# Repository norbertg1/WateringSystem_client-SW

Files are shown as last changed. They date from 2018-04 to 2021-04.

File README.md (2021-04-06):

# Home watering system and weather station

The hardware is based on ESP8266. Its powered from LiFe battery which is chargerd from solar panel. The hardware wakes up every 10 minute (default), and login to mosquito message broker (on ubuntu) and publishes temperature, moisture, flow, etc.. If it is needed it can turn on the irrigation with H-bridge.
The connection between MySQL and Mosquitto is handled with short program written in Python.

**The PCB contains:** EPS8266, LiFe charger, battery voltage sensor, BMP280 sensor, soil moisture sensor, H-bridge for ball valve motor, flow meter.

#### **MySQL structure and settings:**

See: https://github.com/xnorbi/Watering-system/blob/master/server_on_ubuntu/MySQL/database_initialization_commands

For photos see other folder.

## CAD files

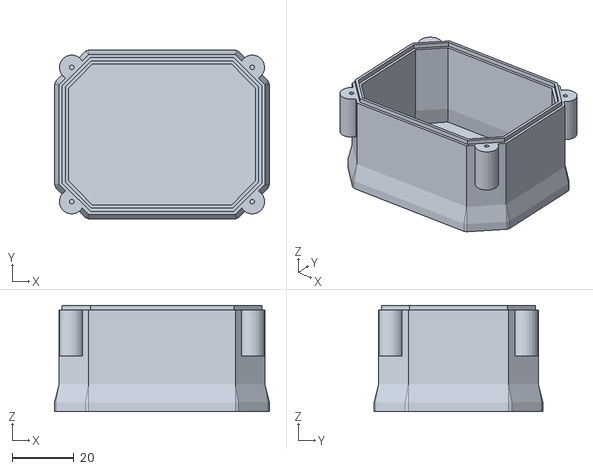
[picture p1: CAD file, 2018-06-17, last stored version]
tető/teto motoros szelepre with solar panel.stl
69.7 x 54.8 x 34.5

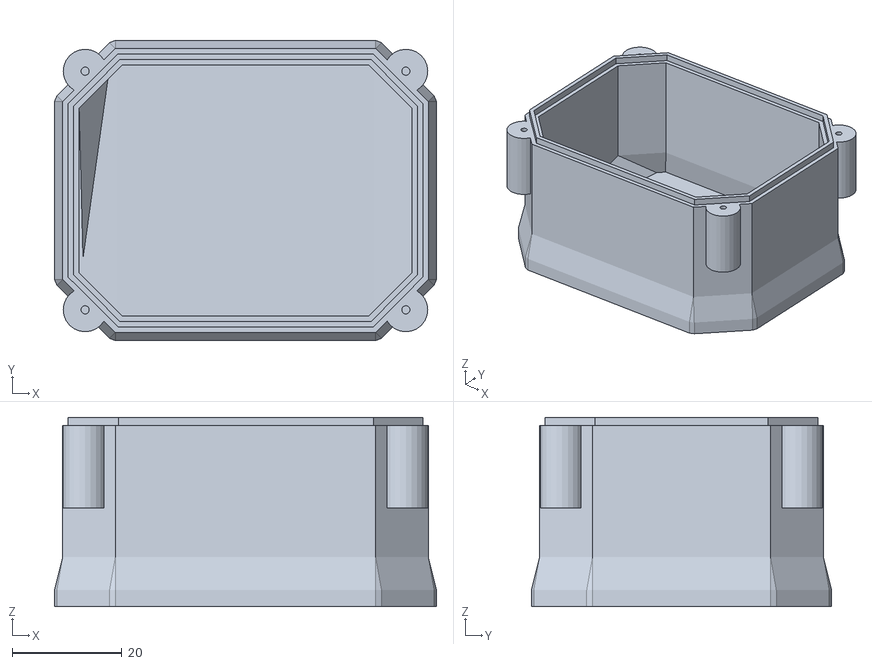
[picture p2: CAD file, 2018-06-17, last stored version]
tető/gal.stl
69.7 x 54.8 x 34.5

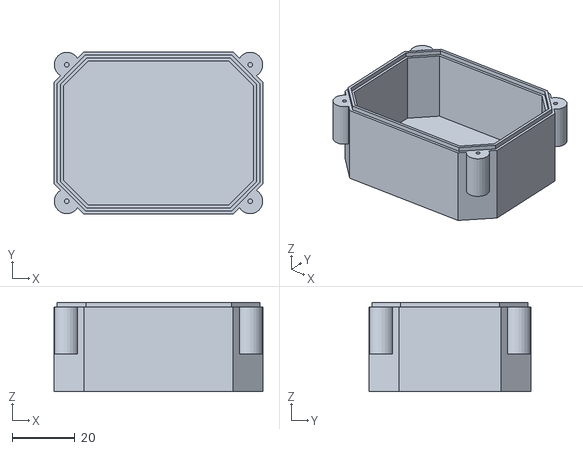
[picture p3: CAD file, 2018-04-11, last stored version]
tető/teto motoros szelepre.stl
66.7 x 51.8 x 28.5

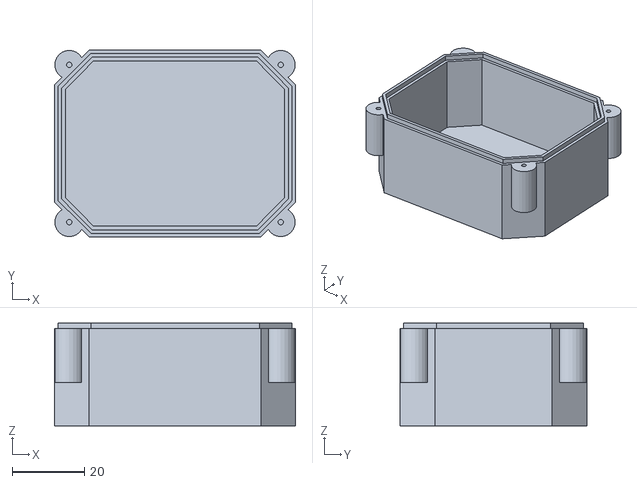
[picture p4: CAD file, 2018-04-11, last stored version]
tető/teto motoros szelepre modified.stl
66.7 x 51.8 x 28.5

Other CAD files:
tető/gal repaired.stl
tető/teto motoros szelepre with solar panel(1).stl
tető/teto motoros szelepre modified.skp
tető/teto motoros szelepre.skp

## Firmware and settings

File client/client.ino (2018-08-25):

/*
   This program login into ESP8266_locsolo_server on ubuntu. Gets the A0 pin status from the server then set it. Also send Vcc voltage and temperature, etc.
   When A0 is HIGH: ESP8266 loggin happens every 30seconds, if it is LOW ---> deep sleep for x seconds
   by Norbi

   v2.4.1 verzióban be kell kapcsolni a Tools --> Debug port ---> Serial beállítást. Ez nélkül ha megszakad a wifi kapcsolat 
   az mqtt_reconnect() funkció csak 3-4 próbálkozás alatt tud sikeresen visszacsatlakozni, felette már nem. Ezt a az opciót bekapcsolva viszont bármennyi próbálkozás után sikeres lehet az újracsatlakozás

   v2.4.1 verzióban Tools --> lwIP Variant --> v1.4 Compile from source opció (többit nem teszteltem, kivéve: defaulnál (v2 Lower Memory) nem működik) szükséges a TLS MQTT titkosított kapcsolat működéséhez

   Wifihez csatlakozás: Bekapcsolni a kapcsolóval, beírni a csatalkozási adatokat, majd ki be kapcsolni ismét a kapcsolóval.
*/
#include "client.h"
#include "certificates.h"
#include "communication.h"


//DHT dht(DHT_PIN, DHT_TYPE);
ESP8266WebServer server (80);
BMP280 bmp;
WiFiClientSecure espClient;
PubSubClient client(espClient);
File f;
#if SZELEP
ADC_MODE(ADC_VCC);
#endif

//const char* host = "192.168.1.100";
const char* mosquitto_user = "titok";
const char* mosquitto_pass = "titok";
char device_id[25];
int mqtt_port= 8883;

const char* serverIndex = "<form method='POST' action='/update' enctype='multipart/form-data'><input type='file' name='update'><input type='submit' value='Update'></form>";
uint32_t voltage;
double T, P;
float temp, temperature, moisture;
int RSSI_value;
int locsolo_state = LOW, on_off_command = LOW;
int sleep_time_seconds = 900;                  //when watering is off, in seconds
int delay_time_seconds = 60;                   //when watering is on, in seconds
int remote_update = 0, remote_log=0;
int flowmeter_int=0;
float flowmeter_volume, flowmeter_velocity;
int valve_timeout=0;
String ver;
int mqtt_done=0;

void setup() {
  if( ESP.getResetReason() != "Power on" && ESP.getResetReason() != "Deep-Sleep Wake" && ESP.getResetReason() != "Software/System restart") alternative_startup();
  Serial.begin(115200);
  delay(50);
  String ID = String(ESP.getChipId(), HEX) + "-" + String(ESP.getFlashChipId(), HEX);
  ID.toCharArray(device_id, 25); 
  format();
  f = create_file();
  println_out("\n-----------------------ESP8266 alive----------------------------------------\n");
  println_out(ESP.getResetReason());
  print_out("ID: ");   println_out(ID);
  print_out("MAC: ");   println_out(WiFi.macAddress());
  get_TempPressure();       //Azért az elején mert itt még nem melegedett fel a szenzor
  setup_pins();
  if (valve_state) valve_turn_off();  
  println_out("Setting up certificates");
  espClient.setCertificate(certificates_esp8266_bin_crt, certificates_esp8266_bin_crt_len);
  espClient.setPrivateKey(certificates_esp8266_bin_key, certificates_esp8266_bin_key_len);
  println_out("Setting up mqtt callback, wifi");
  client.setServer(MQTT_SERVER, mqtt_port);
  client.setCallback(mqtt_callback);
  setup_wifi();
  print_out("IP address:  ");
  println_out(String(WiFi.localIP()));
  print_out("RSSI: ");
  println_out(String(WiFi.RSSI()));
  ver = VERSION;  ver += '.';  ver += SZELEP;
  print_out("version:"); println_out(ver);
  if(voltage > MINIMUM_UPDATE_VOLTAGE) 
  {
    println_out("checking for update");
    t_httpUpdate_return ret = ESPhttpUpdate.update(MQTT_SERVER, 80, "/esp/update/esp8266.php", ver);
    http_update_answer(ret);
  }
  config_time();
}

void loop() {
  //valve_test();
  read_voltage();
  read_moisture();
  mqtt_reconnect();
  //flow_meter_calculate_velocity(); 
  if (client.connected()) {
    char buf_name[50];
    char buf[10];
    mqtt_done=0;
    client.loop();
    println_out("sending temperature");
    mqttsend_d(T, device_id, "/TEMPERATURE", 1);
    println_out("sending moisture");
    mqttsend_d(moisture, device_id, "/MOISTURE", 2);
    println_out("sending RSSI");
    mqttsend_i(WiFi.RSSI(), device_id, "/RSSI");
    println_out("sending voltage,etc..");
    mqttsend_d((float)voltage / 1000, device_id, "/VOLTAGE", 3);
    mqttsend_d(P, device_id, "/PRESSURE", 3);
    mqttsend_s(ver.c_str(), device_id, "/VERSION");
    mqttsend_s(ESP.getResetReason().c_str(), device_id, "/RST_REASON");
    mqttsend_d((float)flowmeter_int / FLOWMETER_CALIB_VOLUME, device_id, "/FLOWMETER_VOLUME_X", 2);    //ez azert kell hogy pontos legyen a ki be kapcsolás
    mqttsend_d((float)millis()/1000, device_id, "/AWAKE_TIME_X", 2);
    mqttsend_i(0, device_id, "/READY_FOR_DATA");
    //delay(3000);
    println_out("Waiting for commands");
    client.loop();
    for (int i = 0; i < 200; i++) {    //Ez mire van? torolni ha nem kell
      delay(100);
      client.loop();                  //Itt várok az adatra, talán szebben is lehetne
      if (mqtt_done == 5) break;
    }
  }

  println_out("Setting up webupdate if set");
  if (remote_update && valve_state() == 0)  web_update(remote_update);
  if (on_off_command && (float)voltage / 1000 > MINIMUM_VALVE_OPEN_VOLTAGE && !(client.state()))  valve_turn_on();
  if (!on_off_command || (float)voltage / 1000 < VALVE_CLOSE_VOLTAGE || (client.state()))        valve_turn_off();
  if (valve_state() != 1) {       //ha a szelep nincs nyitva
    if (client.connected()) {
      char buff_f[10];
      char buf_name[50];
      print_out("Valve state: "); println_out(String(valve_state()));
      mqttsend_i(0, device_id, "/ON_OFF_STATE");
      //mqttsend_d(flowmeter_volume, device_id, "/FLOWMETER_VOLUME", 2);      //ez törölhető csak figyelem van-e indokolatlan megszakítás
      //mqttsend_d(flowmeter_velocity, device_id, "/FLOWMETER_VELOCITY", 2);  //ez törölhető csak figyelem van-e indokolatlan megszakítás
      mqttsend_d((float)millis()/1000, device_id, "/AWAKE_TIME", 2);
      mqttsend_i(0, device_id, "/END");
      delay(100);
      client.disconnect();
    }
    go_sleep(SLEEP_TIME);    
  }
  else   {                        //ha a szelep nyitva van
    print_out("Valve state: "); println_out(String(valve_state()));
    flow_meter_calculate_velocity();
    mqtt_reconnect();
    if (client.connected()) {
      char buff_f[10];
      char buf_name[50];
      client.loop();
      mqttsend_i(1, device_id, "/ON_OFF_STATE");
      mqttsend_d(flowmeter_volume, device_id, "/FLOWMETER_VOLUME", 2);
      mqttsend_d(flowmeter_velocity, device_id, "/FLOWMETER_VELOCITY", 2);
      mqttsend_d((float)millis()/1000, device_id, "/AWAKE_TIME", 2);
      mqttsend_i(0, device_id, "/END");
      client.loop();
      delay(100);
      client.disconnect();
    }
    print_out("time in awake state: "); print_out(String((float)millis()/1000)); println_out(" s");
    println_out("delay");
    delay(DELAY_TIME);
    on_off_command = 0;
    detachInterrupt(FLOWMETER_PIN);
    digitalWrite(GPIO15, LOW);
    get_TempPressure();         //Nyitott szelepnél minden újracsatlakozásnál mérek hőmérsékletet és légnyomást
    digitalWrite(GPIO15, HIGH);
    attachInterrupt(FLOWMETER_PIN, flow_meter_interrupt, FALLING);
  }
}

void valve_turn_on() {
#if SZELEP
  digitalWrite(GPIO15, HIGH); //VOLTAGE BOOST
  println_out("Valve_turn_on()");
  pinMode(FLOWMETER_PIN, INPUT);
  attachInterrupt(FLOWMETER_PIN, flow_meter_interrupt, FALLING);
  digitalWrite(VALVE_H_BRIDGE_RIGHT_PIN, 0);
  digitalWrite(VALVE_H_BRIDGE_LEFT_PIN, 1);
  uint32_t t = millis();
  while (!digitalRead(VALVE_SWITCH_TWO) && (millis() - t) < MAX_VALVE_SWITCHING_TIME) {
    delay(100);
  }
  if (valve_state) locsolo_state = HIGH;
  if((millis() - t) > MAX_VALVE_SWITCHING_TIME)  {println_out("Error turn on timeout reached");  valve_timeout=1;}
#endif
}

void valve_turn_off() {
#if SZELEP
  bool closing_flag=0;
  println_out("Valve_turn_off");
  uint16_t cnt = 0;
  digitalWrite(VALVE_H_BRIDGE_RIGHT_PIN, 1);
  digitalWrite(VALVE_H_BRIDGE_LEFT_PIN, 0);
  uint32_t t = millis();
  while (!digitalRead(VALVE_SWITCH_ONE) && (millis() - t) < MAX_VALVE_SWITCHING_TIME) {
    delay(100);
    closing_flag=1;
  }
  if (closing_flag==1)  {
    flow_meter_calculate_velocity();
    mqttsend_d(flowmeter_volume, device_id, "/FLOWMETER_VOLUME", 2);
    mqttsend_d(flowmeter_velocity, device_id, "/FLOWMETER_VELOCITY", 2);
  }
  if (!valve_state) locsolo_state = LOW;
  digitalWrite(GPIO15, LOW);  //VOLTAGE_BOOST
  detachInterrupt(FLOWMETER_PIN); 
  if((millis() - t) > MAX_VALVE_SWITCHING_TIME)  {println_out("Error turn off timeout reached");  valve_timeout=1;}
#endif
}

int valve_state() {
#if SZELEP
  int ret=0;
  if(digitalRead(VALVE_SWITCH_TWO) && !digitalRead(VALVE_SWITCH_ONE))    {ret=1;}
  if(!digitalRead(VALVE_SWITCH_TWO) && digitalRead(VALVE_SWITCH_ONE))    {ret=0;}
  if(digitalRead(VALVE_SWITCH_TWO) && digitalRead(VALVE_SWITCH_ONE))     {ret=2;}
  if(!digitalRead(VALVE_SWITCH_TWO) && !digitalRead(VALVE_SWITCH_ONE))   {ret=3;}
  if(valve_timeout) { ret+=10;}
  return ret;  
  //return digitalRead(VALVE_SWITCH_TWO);
#else
  return 0;
#endif
}

void valve_test(){
  while(1){
    valve_turn_off();
    valve_turn_on();
    delay(100);
    }
}

void setup_pins(){
  pinMode(GPIO15, OUTPUT);
  pinMode(VALVE_H_BRIDGE_RIGHT_PIN, OUTPUT);
  pinMode(VALVE_H_BRIDGE_LEFT_PIN, OUTPUT);
  pinMode(RXD_VCC_PIN, OUTPUT);
  pinMode(VALVE_SWITCH_ONE, INPUT);
  pinMode(VALVE_SWITCH_TWO, INPUT);
}

void go_sleep_callback(WiFiManager *myWiFiManager){
  go_sleep(SLEEP_TIME_NO_WIFI);
}

void go_sleep(float microseconds){
  valve_turn_off();
  //WiFi.disconnect();  //nehezen akart ezzel visszacsatlakozni
  if (remote_log)  send_log();
  espClient.stop();
  print_out("time in awake state: "); print_out(String((float)millis()/1000)); println_out(" s");
  Serial.print("time in awake state: "); Serial.print((float)millis()/1000); Serial.println(" s");
  if(microseconds - micros() > MINIMUM_DEEP_SLEEP_TIME){  //korrekcio a bekapcsolva levo idore 
    microseconds = microseconds - micros();
  }
 
  time_t now = time(nullptr);
  if(now == 0 && rtcData.valid){
    rtcData.epoch += (time_t)millis()/1000; //Az RTCben tárolt epoch értékehz hozzáadom a bekapolcst állapotban levő időhosszt
    now = rtcData.epoch;  //Az RTCben tárolt érték lesz a jelenlegi időpont
  }
  else rtcData.epoch = now;
  rtcData.epoch += (time_t)microseconds/1000000; //Az RTCbet tárolt epoch értékét megnövelem az deepsleep állapotban levő időhosszal
  println_out("");
  println_out(ctime(&now));
  RTC_save();
  print_out("Entering in deep sleep for: "); print_out(String((float)microseconds/1000000)); println_out(" s");
  close_file();
  delay(100);
  ESP.deepSleep(microseconds); //az elozo sort vonom ki
  delay(100);
}

void flow_meter_interrupt(){
  flowmeter_int++;
}

void flow_meter_calculate_velocity(){
  static int last_int_time = 0, last_int = 0;;

  flowmeter_volume = (float)flowmeter_int / FLOWMETER_CALIB_VOLUME;
  flowmeter_velocity = ((float)(flowmeter_int - last_int) / (((int)millis() - last_int_time)/1000))/FLOWMETER_CALIB_VELOCITY;
  //if (flowmeter_volume == 0) flowmeter_velocity=0;
  last_int_time = millis();
  last_int = flowmeter_int;

  print_out("Flowmeter volume: "); print_out(String(flowmeter_volume)); println_out(" L");
  print_out("Flowmeter velocity: "); print_out(String(flowmeter_velocity)); println_out(" L/min");
}

void read_voltage(){
#if !SZELEP  
  digitalWrite(GPIO15, 0);        //FSA3157 digital switch
  digitalWrite(RXD_VCC_PIN, 1);
  delay(100); //2018.aug.25
  voltage = 0;
  for (int j = 0; j < 20; j++) voltage+=analogRead(A0); // for new design
  //voltage = (voltage / 20)*4.7272*1.039;                         //4.7272 is the resistor divider value, 1.039 is empirical for ESP8266
  voltage = (voltage / 20)*4.7272*0.957;                                 //82039a-1640ef, 2018.aug.15
  print_out("Voltage:");  println_out(String(voltage));
  digitalWrite(RXD_VCC_PIN, 0);
#else
  voltage = 0;
  for (int j = 0; j < 10; j++) {voltage+=ESP.getVcc(); /*Serial.println(ESP.getVcc());*/}
  voltage = (voltage / 10) - VOLTAGE_CALIB; //-0.2V
  print_out("Voltage:");  println_out(String(voltage));
#endif
  }

void read_moisture(){  
#if !SZELEP
  digitalWrite(GPIO15, 1);          //FSA3157 digital switch
  delay(100);
  moisture = 0;
  for (int j = 0; j < 20; j++) moisture += analogRead(A0);
  moisture = (((float)moisture / 20) / 1024.0) * 100;
  print_out("Moisture:");  println_out(String(moisture));
  digitalWrite(GPIO15, 0);
  delay(10);
#endif  
}

void get_TempPressure(){
  
  if (!bmp.begin(SDA,SCL))  {
    println_out("BMP init failed!");
    bmp.setOversampling(16);
  }
  else {println_out("BMP init success!"); bmp.setOversampling(16);}
  double t = 0, p = 0;
  for (int i = 0; i < 3; i++) {
    delay(bmp.startMeasurment());
    bmp.getTemperatureAndPressure(T, P);
    t += T;
    p += P;
  }
  T = t / 3;
  P = p / 3;
  print_out("T=");     print_out(String(T));
  print_out("   P=");  println_out(String(P));
}

void http_update_answer(t_httpUpdate_return ret){
  switch(ret) {
    case HTTP_UPDATE_FAILED:
      println_out("[update] Update failed.");
      break;
    case HTTP_UPDATE_NO_UPDATES:
      println_out("[update] Update no Update.");
      break;
    case HTTP_UPDATE_OK:
      println_out("[update] Update ok."); // may not called we reboot the ESP
      break;    
  }
}

File create_file(){
#if FILE_SYSTEM  
  SPIFFS.begin();
  char buff[13];
  sprintf (buff, "%s%s", "/", device_id);
  File f = SPIFFS.open(buff, "a+");
  if (!f) {
    Serial.println("log file open failed");
    SPIFFS.remove(buff);
    format_now();
  }
  if(f.size() > MAX_LOG_FILE_SIZE){      //Ha tul nagy
    f.close();
    SPIFFS.remove(buff);
    File f = SPIFFS.open(buff, "a+");
  }
  f.print("\nfile size:");
  f.print(f.size());
  Serial.print("\nfile size:");
  Serial.print(f.size());
  return f;
#endif
}

void close_file(){
#if FILE_SYSTEM
  f.close();
#endif
}

void print_out(String str){
#if SERIAL_PORT  
  Serial.print(str);
#endif
#if FILE_SYSTEM  
  f.print(str);
#endif
}

void println_out(String str){
#if SERIAL_PORT
  Serial.println(str);
  Serial.print((float)millis()/1000); Serial.print(":");
#endif
#if FILE_SYSTEM
  f.println(str);
  f.print((float)millis()/1000); f.print(":");
#endif
}

void config_time(){
#ifdef CONFIG_TIME
  configTime(2 * 3600, 3600, "pool.ntp.org", "time.nist.gov", "time.google.com");
  print_out("Get current time request");
#endif
}

void format(){
#if FILE_SYSTEM
  SPIFFS.begin();
  if (!SPIFFS.exists("/formok")) {
    Serial.println("Please wait 30 secs for SPIFFS to be formatted");
    if(SPIFFS.format()) Serial.println("Spiffs formatted");
    File file = SPIFFS.open("/formok", "w");
    if (!file) {
        Serial.println("file open failed");
    } else {
        file.println("Format Complete");
        file.close();
        Serial.println("format file written and closed");
    }
  } else {
    println_out("SPIFFS is formatted. Moving along...");
  }
#endif
}

void format_now(){
#if FILE_SYSTEM
  if(SPIFFS.format()) Serial.println("Spiffs formatted");
  else Serial.println("Spiffs format failed");
#endif
}

void alternative_startup(){
  SPIFFS.end();
  setup_wifi();
  t_httpUpdate_return ret = ESPhttpUpdate.update(MQTT_SERVER, 80, "/esp/update/esp8266.php", ver);
  http_update_answer(ret);
}

void RTC_save(){
  print_out("\nSaving BSSID, channel and time to RTC memory\n");
  rtcData.crc32 = calculateCRC32( ((uint8_t*)&rtcData) + 4, sizeof( rtcData ) - 4 );
  ESP.rtcUserMemoryWrite( 0, (uint32_t*)&rtcData, sizeof( rtcData ) );
}

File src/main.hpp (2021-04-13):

#ifndef MAIN_H
#define MAIN_H
/*
   This program login into ESP8266_locsolo_server on ubuntu. Gets the A0 pin status from the server then set it. Also send Vcc voltage and temperature, etc.
   When A0 is HIGH: ESP8266 loggin happens every 30seconds, if it is LOW ---> deep sleep for x seconds
   by Norbi

   3V alatt ne nyisson ki a szelep, de ha nyitva van akkor legyen egy deltaU feszĂĽltsĂ©g ami alatt csukodk be (pl 2.9V)
*/
#define ESP32
#include <Arduino.h>
#include "FS.h"
#include <PubSubClient.h>
//#include <ESP8266httpUpdate.h>
#include "HTTPUpdate.h"

//----------------------------------------------------------------settings---------------------------------------------------------------------------------------------------------------------------------------------//
#define WIFI_CONNECTION_TIMEOUT           30                              //Time for connecting to wifi in seconds
#define WIFI_CONFIGURATION_PAGE_TIMEOUT   300                             //when cannot connect to saved wireless network, in seconds, this is the time until we can set new SSID in seconds
#define MAX_VALVE_SWITCHING_TIME_SECONDS  20                              //The time when valve is switched off in case of broken microswitch or mechanical failure in seconds
#define WEB_UPDATE_TIMEOUT_SECONDS        300                             //The time out for web update server in seconds 
#define SLEEP_TIME_NO_WIFI_SECONDS        30//3600                            //When cannot connect to wifi network, sleep time between two attempts
#define MINIMUM_DEEP_SLEEP_TIME_SECONDS   60                              //in seconds
//---------------------------------------------------------------End of settings---------------------------------------------------------------------------------------------------------------------------------------//

//------------------------------------------------------------------------Do not edit------------------------------------------------------------------------------------------------
#define MINIMUM_DEEP_SLEEP_TIME           (long long) MINIMUM_DEEP_SLEEP_TIME_SECONDS * 1000000
#define SLEEP_TIME_NO_WIFI                (long long) SLEEP_TIME_NO_WIFI_SECONDS * 1000000    
#define SLEEP_TIME                        (long long) sleep_time_seconds * 1000000            //when watering is off, in microseconds
#define DELAY_TIME                        delay_time_seconds * 1000               //when watering is on, in miliseconds
#define WEB_UPDATE_TIMEOUT                WEB_UPDATE_TIMEOUT_SECONDS  * 1000      //time out for web update server
#define MAX_VALVE_SWITCHING_TIME          MAX_VALVE_SWITCHING_TIME_SECONDS*1000
#define DHT_TYPE                          DHT22
/*#define DHT_PIN                           0     //<---- innet kikommentezni oldhoz
#define VALVE_H_BRIDGE_RIGHT_PIN          12
#define VALVE_H_BRIDGE_LEFT_PIN           4
#define VALVE_SWITCH_ONE                  14
#define VALVE_SWITCH_TWO                  13
#define GPIO15                            15      //ennek kene lennie a voltage boost EN pinnek és az FSA3157 switch pinnek is
#define SCL                               5
#define SDA                               2
#define FLOWMETER_PIN                     5  */   //<---- eddig
#define RXD_VCC_PIN                       3
#define TXD_PIN                           1
#define VOLTAGE_CALIB                     230
#define MQTT_SERVER                       "locsol.dynamic-dns.net"
#define FTP_SERVER                        "192.168.1.101"
#define FLOWMETER_CALIB_VOLUME            450.0 //Pulses per Liter: 450
#define FLOWMETER_CALIB_VELOCITY          7.5   //Pulse frequency (Hz) / 7.5 = flow rate in L/min
#define MINIMUM_UPDATE_VOLTAGE            3.1   //If valve is closed
#define MINIMUM_VALVE_OPEN_VOLTAGE        3.1   //If valve is closed
#define VALVE_CLOSE_VOLTAGE               3.05   //If valve is open
#define MAX_LOG_FILE_SIZE                 409600
#define SZELEP                            0
#define FILE_SYSTEM                       0
#define SERIAL_PORT                       1
#define CONFIG_TIME                       1
//--------------------------------------------------------------------End----------------------------------------------------------------------------------------------------------------------------------------------------//
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

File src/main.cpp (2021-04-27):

/*
 
   Wifihez csatlakozás: Bekapcsolni a kapcsolóval, beírni a csatalkozási adatokat, majd ki be kapcsolni ismét a kapcsolóval.

*/
#include "main.hpp"

WiFiClient WifiClient;
File f;

//const char* host = "192.168.1.100";
char device_id[16];
int mqtt_port = 8883;
int sleep_time_seconds = 900;                  //when watering is off, in seconds
int delay_time_seconds = 60;                   //when watering is on, in seconds
int remote_update = 0, remote_log=0;

String ver;
String ID ;

WiFiClientSecure WifiSecureClient;
mqtt mqtt_client(WifiSecureClient);

valve_control Valve;
flowmeter Flowmeter;
voltage Battery;
moisture Soil;
thermometer Thermometer;
humiditySensor HumiditySensor;
pressureSensor PressureSensor;

void setup() {
  Serial.begin(115200);
  println_out("\n-----------------------ESP8266 alive-----------------------------------------\n");
  println_out("Reset reason for CPU0:");
  println_out(reset_reason(0));
  println_out("Reset reason for CPU1:");
  println_out(reset_reason(1));
  if( reset_reason(0) != "POWERON_RESET" && reset_reason(0) != "SW_RESET" && reset_reason(0) != "DEEPSLEEP_RESET") alternative_startup();  //Ez azért hogy ha hiba volna a programban akkor is újarindulás után OTAn frissíthető váljon a rendszer
  ID = String((uint32_t)(ESP.getEfuseMac() >> 32), HEX) + String((uint32_t)ESP.getEfuseMac(), HEX);  //String function doesnt know uint64_t
  ID.toCharArray(device_id, 16);
  format();
  f = create_file();
  RTC_validateCRC();
  setup_wifi();
  print_out("SDK: ");   println_out(ESP.getSdkVersion());
  print_out("Version: "); println_out(VERSION);
  print_out("ID: ");   println_out(ID);
  print_out("MAC: ");   println_out(WiFi.macAddress());
  setup_pins();
  Thermometer.read();
  HumiditySensor.read();
  PressureSensor.read();
  Battery.read_voltage();
  Soil.read_moisture();
  //if (Valve.state() && !Valve.winter_state) valve_turn_off();    //EEPROMba vagy SPIFFbe tarolni, hogy epp winter state van-e? utanna ellenorizni!!!
  if (Valve.state()) Valve.turn_off();
  Wait_for_WiFi();
  print_out("IP address:  ");
  println_out(String(WiFi.localIP().toString()));
  print_out("RSSI: ");
  println_out(String(WiFi.RSSI()));
  config_time();
  WifiSecureClient.setCACert(root_CA_cert);
  WifiSecureClient.setPrivateKey(ESP_RSA_key);
  WifiSecureClient.setCertificate(ESP_CA_cert);
  mqtt_client.setServer(MQTT_SERVER, mqtt_port);
  mqtt_client.setCallback(mqtt_callback);
  Serial.print("WifiSecureClient: "); Serial.println(WifiSecureClient.remoteIP());
  if((float)Battery.voltage/1000 > MINIMUM_UPDATE_VOLTAGE) 
  {
    println_out("Checking for update!");
    t_httpUpdate_return ret = httpUpdate.update(WifiClient,MQTT_SERVER, 80, "/esp/update/update.php", VERSION);
    http_update_answer(ret);
  }
}

void loop() {
  //Valve.test();
  Valve.on_off_command = 0;
  mqtt_client.reconnect();
  if (mqtt_client.connected()) {
    send_measurements_to_server();
    mqtt_client.waiting_for_messages(5); //number off messages we waiting for
  }
  if (remote_update && (Valve.state() == 0 || Valve.winter_state == 1))  {webupdate(5); println_out("\nSetting up Webupdate");}
  if (Valve.winter_state == 1)  Valve.winter_mode(); 
  if (Valve.on_off_command && ((float)Battery.voltage / 1000) > MINIMUM_VALVE_OPEN_VOLTAGE && !(mqtt_client.state()))  Valve.turn_on();
  if (!Valve.on_off_command || ((float)Battery.voltage / 1000) < VALVE_CLOSE_VOLTAGE || (mqtt_client.state()))        Valve.turn_off();
  delay(100);
  if ((Valve.state() == 1) || (Valve.state() == 14))  Valve.is_open(); //ha a szelep nyitva van
  else                                                Valve.is_closed();

  print_out("Time in awake state: "); print_out(String((float)millis()/1000)); println_out(" s");
  println_out("Delay");
  delay(DELAY_TIME);
  Valve.on_off_command = 0;
  detachInterrupt(FLOWMETER_PIN);
  digitalWrite(EN_5V, LOW);
  Thermometer.read();         //Nyitott szelepnél minden újracsatlakozásnál mérek hőmérsékletet és légnyomást
  digitalWrite(EN_5V, HIGH);
  attachInterrupt(FLOWMETER_PIN, flowmeter_callback, FALLING);
}

void flowmeter_callback(){
  Flowmeter.flowmeter_callback();
}

void mqtt_callback(char* topic, byte* payload, unsigned int length){
  mqtt_client.callback_function(topic, payload, length);
}

void send_measurements_to_server(){
  mqtt_client.loop();
  println_out("sending temperature");
  mqtt_client.send_d(Thermometer.temperature, device_id, "/TEMPERATURE", 1);
  println_out("sending moisture");
  mqtt_client.send_d(Soil.moisture, device_id, "/MOISTURE", 2);
  println_out("sending RSSI");
  mqtt_client.send_i(WiFi.RSSI(), device_id, "/RSSI");
  println_out("sending voltage,etc..");
  mqtt_client.send_d((float)Battery.voltage / 1000, device_id, "/VOLTAGE", 3);
  mqtt_client.send_d(0, device_id, "/PRESSURE", 3);
  mqtt_client.send_s(ver.c_str(), device_id, "/VERSION");
  mqtt_client.send_s(reset_reason(0).c_str(), device_id, "/RST_REASON");
  mqtt_client.send_d(Flowmeter.get_volume(), device_id, "/FLOWMETER_VOLUME_X", 2);    //ez azert kell hogy pontos legyen a ki be kapcsolás
  mqtt_client.send_d((float)millis()/1000, device_id, "/AWAKE_TIME_X", 2);
  mqtt_client.send_i(0, device_id, "/READY_FOR_DATA");
}

void setup_pins(){
  pinMode(EN_5V, OUTPUT);
  pinMode(VALVE_H_BRIDGE_RIGHT_PIN, OUTPUT);
  pinMode(VALVE_H_BRIDGE_LEFT_PIN, OUTPUT);
  pinMode(VALVE_SWITCH_ONE, INPUT);
  pinMode(VALVE_SWITCH_TWO, INPUT);
}

void go_sleep_callback(/*WiFiManager *myWiFiManager*/void *){
  go_sleep(SLEEP_TIME_NO_WIFI, 0);
}

void go_sleep(float microseconds, int winter_state){
  if (!Valve.winter_state) {
    println_out("Winter_state.");
    Valve.turn_off();
  }
  //WiFi.disconnect();  //nehezen akart ezzel visszacsatlakozni
  //if (remote_log)  send_log();
  print_out("time in awake state: "); print_out(String((float)millis()/1000)); println_out(" s");
  if(microseconds - micros() > MINIMUM_DEEP_SLEEP_TIME){  //korrekcio a bekapcsolva levo idore 
    microseconds = microseconds - micros();
  }

  time_t now = time(nullptr);
  if( WiFi.status() != WL_CONNECTED ){//"Power on"
    rtcData.epoch += (time_t)millis()/1000; //Az RTCben tárolt epoch értékehz hozzáadom a bekapolcst állapotban levő időhosszt
    now = rtcData.epoch;  //Az RTCben tárolt érték lesz a jelenlegi időpont
  }
  else rtcData.epoch = now;
  rtcData.epoch += (time_t)microseconds/1000000; //Az RTCbet tárolt epoch értékét megnövelem az deepsleep állapotban levő időhosszal
  println_out(ctime(&now));
  RTC_saveCRC();
  print_out("Previous unsuccessful wifi connection attempts: "); print_out((String)rtcData.attempts);
  print_out("Entering in deep sleep for: "); print_out(String((float)microseconds/1000000)); println_out(" s");
  WifiSecureClient.stop();
  close_file();
  delay(100);
  ESP.deepSleep(30*1000000);
  ESP.deepSleep(microseconds); //az elozo sort vonom ki
  delay(100);
}

void print_out(String str){
#if SERIAL_PORT  
  Serial.print(str);
#endif
#if FILE_SYSTEM  
  f.print(str);
#endif
}
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

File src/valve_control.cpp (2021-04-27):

#include "valve_control.hpp"
#include "main.hpp"

void valve_control::turn_on() {
#if SZELEP
  digitalWrite(EN_5V, HIGH); //VOLTAGE BOOST
  println_out("Valve_turn_on()");
  pinMode(FLOWMETER_PIN, INPUT);
  attachInterrupt(FLOWMETER_PIN, flowmeter_callback, FALLING);
  digitalWrite(VALVE_H_BRIDGE_RIGHT_PIN, 0);
  digitalWrite(VALVE_H_BRIDGE_LEFT_PIN, 1);
  uint32_t t = millis();
  while (!digitalRead(VALVE_SWITCH_TWO) && (millis() - t) < MAX_VALVE_SWITCHING_TIME) {
    delay(100);
  }
  if (state()) locsolo_state = HIGH;
  if((millis() - t) > MAX_VALVE_SWITCHING_TIME)  {println_out("Error turn on timeout reached");  valve_timeout=1;}
#endif
}

void valve_control::turn_off() {
#if SZELEP
  bool closing_flag=0;
  println_out("Closing Valve");
  uint16_t cnt = 0;
  digitalWrite(VALVE_H_BRIDGE_RIGHT_PIN, 1);
  digitalWrite(VALVE_H_BRIDGE_LEFT_PIN, 0);
  uint32_t t = millis();
  while (!digitalRead(VALVE_SWITCH_ONE) && (millis() - t) < MAX_VALVE_SWITCHING_TIME) {
    delay(100);
    closing_flag=1;
  }
  if (closing_flag==1)  {
    mqtt_client.send_d(Flowmeter.get_volume(), device_id, "/FLOWMETER_VOLUME", 2);
    mqtt_client.send_d(Flowmeter.get_velocity(), device_id, "/FLOWMETER_VELOCITY", 2);
  }
  if (!state()) locsolo_state = LOW;
  digitalWrite(EN_5V, LOW);  //VOLTAGE_BOOST
  detachInterrupt(FLOWMETER_PIN); 
  if((millis() - t) > MAX_VALVE_SWITCHING_TIME)  {println_out("Error turn off timeout reached");  valve_timeout=1;}
#endif
}

int valve_control::state() {
#if SZELEP
  int ret=0;
  print_out("VALVE_SWITCH_ONE:"); println_out(String(digitalRead(VALVE_SWITCH_ONE)));
  print_out("VALVE_SWITCH_TWO:"); println_out(String(digitalRead(VALVE_SWITCH_TWO)));

  if(digitalRead(VALVE_SWITCH_TWO) && !digitalRead(VALVE_SWITCH_ONE))                         {ret=1;}  //Ha nyitva van
  if(digitalRead(VALVE_SWITCH_TWO) && !digitalRead(VALVE_SWITCH_ONE) && winter_state == 1)    {ret=2;}
  if(!digitalRead(VALVE_SWITCH_TWO) && digitalRead(VALVE_SWITCH_ONE))                         {ret=0;}
  if(digitalRead(VALVE_SWITCH_TWO) && digitalRead(VALVE_SWITCH_ONE))                          {ret=12;}
  if(!digitalRead(VALVE_SWITCH_TWO) && !digitalRead(VALVE_SWITCH_ONE))                        {ret=13;}
  if (((float)Battery.voltage / 1000) <= VALVE_CLOSE_VOLTAGE) ret = 5;
  if (((float)Battery.voltage / 1000) <= MINIMUM_VALVE_OPEN_VOLTAGE) ret += 4;
  if(valve_timeout) {ret+=10;}
  print_out("Voltage: "); print_out(String(Battery.voltage));
  print_out(", valve_timeout flag: "); print_out(String(valve_timeout));
  print_out(", Valve state: "); println_out(String(ret));
  return ret;  //Nyitott állapot lehet ret = 1 vagy ret = 14
  //return digitalRead(VALVE_SWITCH_TWO);
#else
  return 0;
#endif
}

void valve_control::is_open(){       //ha a szelep nyitva van
    print_out("Valve state: "); println_out(String(state()));
    mqtt_client.reconnect();
    if (mqtt_client.connected()) {
      print_out("szelep nyitva");
      mqtt_client.loop();
      mqtt_client.send_i(on_off_command, device_id, "/ON_OFF_STATE"); //ez elég fura, utánnajárni
      mqtt_client.send_d(Flowmeter.get_volume(), device_id, "/FLOWMETER_VOLUME", 2);
      mqtt_client.send_d(Flowmeter.get_velocity(), device_id, "/FLOWMETER_VELOCITY", 2);
      mqtt_client.send_d((float)millis()/1000, device_id, "/AWAKE_TIME", 2);
      mqtt_client.send_i(0, device_id, "/END");
      mqtt_client.loop();
      delay(100);
      mqtt_client.disconnect();
    }
  }

void valve_control::is_closed(){                                                   //ha a szelep nincs nyitva
    if (mqtt_client.connected()) {
      print_out("\nszelept nincs nyitva\n");
      mqtt_client.reconnect();
      mqtt_client.send_i(state(), device_id, "/ON_OFF_STATE");
      mqtt_client.send_d((float)millis()/1000, device_id, "/AWAKE_TIME", 2);
      mqtt_client.send_i(0, device_id, "/END");
      delay(100);
      mqtt_client.disconnect();
    }
    go_sleep(SLEEP_TIME, 0);
  }

  void valve_control::winter_mode(){
  turn_on();
  if (mqtt_client.connected()) {
    mqtt_client.reconnect();
    print_out("Winter mode\n"); print_out("Valve state: "); println_out(String(state()));
    mqtt_client.send_i(state(), device_id, "/ON_OFF_STATE");
    mqtt_client.send_d((float)millis()/1000, device_id, "/AWAKE_TIME", 2);
    mqtt_client.send_i(0, device_id, "/END");
    delay(100);
    mqtt_client.disconnect();
    }
    go_sleep(SLEEP_TIME, 1);
}

void valve_control::test(){
  while(1){
    turn_off();
    turn_on();
    delay(100);
    }
}
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

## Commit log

2016-01-19 temperature and temperature average values at /dht_status where not synchronized with temperature average values at main page - FIXED
2016-01-19 temperature and temperature average values at /dht_status where not synchronized with temperature average values at main page - FIXED 2
2016-08-13 Daylight saving bug fixed, schematic picture added
    [client.ino]
2016-09-05 PCB modification
2016-09-20 New PCB design, code accomodation in progress
2016-10-03 client PCB final version
2016-10-12 +logging server start year,month,day +PCB improvement
2016-11-04 PCB improvement, bugfix
2016-11-14 +Altium, better file structure
    [Locsolo.PrjPcb, PCB.PcbDoc, Schematic.SchDoc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]
2016-12-13 PCB v0.1 sent to factory.
    [Locsolo.PrjPcb, PCB.PcbDoc, Schematic.SchDoc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]
2017-01-05 PCB: minor bugs fixed
    [Locsolo.PrjPcb, PCB.PcbDoc, Schematic.SchDoc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]
2017-01-06 modified battery protect circuit
    [PCB.PcbDoc, Schematic.SchDoc]
2017-09-01 Initial commit for ubuntu server mysql handler python code. Communication changed on MQTT channel.
    [Schematic.SchDoc, components.SchLib]
2017-09-02 Imptelented MQTT, Initial commit ubuntu server mysql handle python code.
    [Schematic.SchDoc]
2017-11-02 Working battery managment with two TC54VN voltage detectors
    [Locsolo.PrjPcb, PCB.PcbDoc, Schematic.SchDoc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]
2017-11-09 Ready for PCB prototyp ver.2 factoring
    [Locsolo.PrjPcb, PCB.PcbDoc, Schematic.SchDoc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]
2017-12-10 +Mosquito configuration, some bugfix and changes
    [Locsolo.PrjPcb, PCB.PcbDoc]
2018-02-26 change: AP is disabled after deep sleep when the ESP cant connect to wifi network. Only case for AP is when: there is no know wifi network AND turn on/off switch was happend (or battery is recharged 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
    [Locsolo.PrjPcb, PCB.PcbDoc, Rendelés_1.xlsx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]
2018-02-26 Deep sleep time corrected with wake up time. Now its more precise. Up to now it was 10s shift in deepsleep time, now it was eliminated.
    [client.h, client.ino, communication.ino]
2018-04-11 Itt még van device name
    [PCB.PcbDoc, Schematic.SchDoc, teto motoros szelepre modified.skp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]
2018-05-08 velocity and moisture issue fixed
    [client.ino]
2018-05-29 +scheduled_irrigation_one_time, +irrigation on temperature, +openweathermap
    [Schematic.SchDoc]
2018-06-17 many small changes
    [gal repaired.stl, gal.stl, teto motoros szelepre with solar panel(1).stl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]
2018-07-02 some structural changes. Readme updated.
    [Locsolo.PrjPcb, PCB-sensor.PcbDoc, PCB.PcbDoc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]
2018-08-28 fix altium ignore, etc.
    [Locsolo.PrjPcb, PCB-sensor.PcbDoc, PCB.PcbDoc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]
2018-09-06 some improvments
    [Locsolo.PrjPcb, PCB.PcbDoc, Schematic.SchDoc]
2018-10-23 Rewrited MySQL server code
    [PCB.PcbDoc, Schematic.SchDoc]
2019-03-28 First commit in the year after long time.
    [PCB.PcbDoc]
2019-08-24 Some major changes.
    [Locsolo.PrjPcb, PCB.PcbDoc, Schematic.SchDoc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]
2020-04-24 In this commit hardware and software git separated.
    [Locsolo.PrjPcb, PCB-sensor.PcbDoc, PCB.PcbDoc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]
2020-12-01 fixed issue caused by bracket in main.c, clien version changed to v1.68. Certificate generator commands fixed. PHP update script log file moved and added some other log cases.
    [main.cpp, main.hpp]
2021-04-06 Porting code to ESP32, now is very messy, unusable code.
2021-04-06 Porting code to ESP32, still very messy, unusable code, worked on TLS.
2021-04-07 Porting code to ESP32, still very messy, unusable code.
2021-04-09 Porting code to ESP32, completed update from server, the built binary gets the newest version name.
2021-04-13 Porting code to ESP32, moving some code to OOP code.
2021-04-17 Current version number is derived from current date and time. Update from WEB working. Some function moved into new libraries.
2021-04-27 PIN mapping changed according to ESP32 new design.
